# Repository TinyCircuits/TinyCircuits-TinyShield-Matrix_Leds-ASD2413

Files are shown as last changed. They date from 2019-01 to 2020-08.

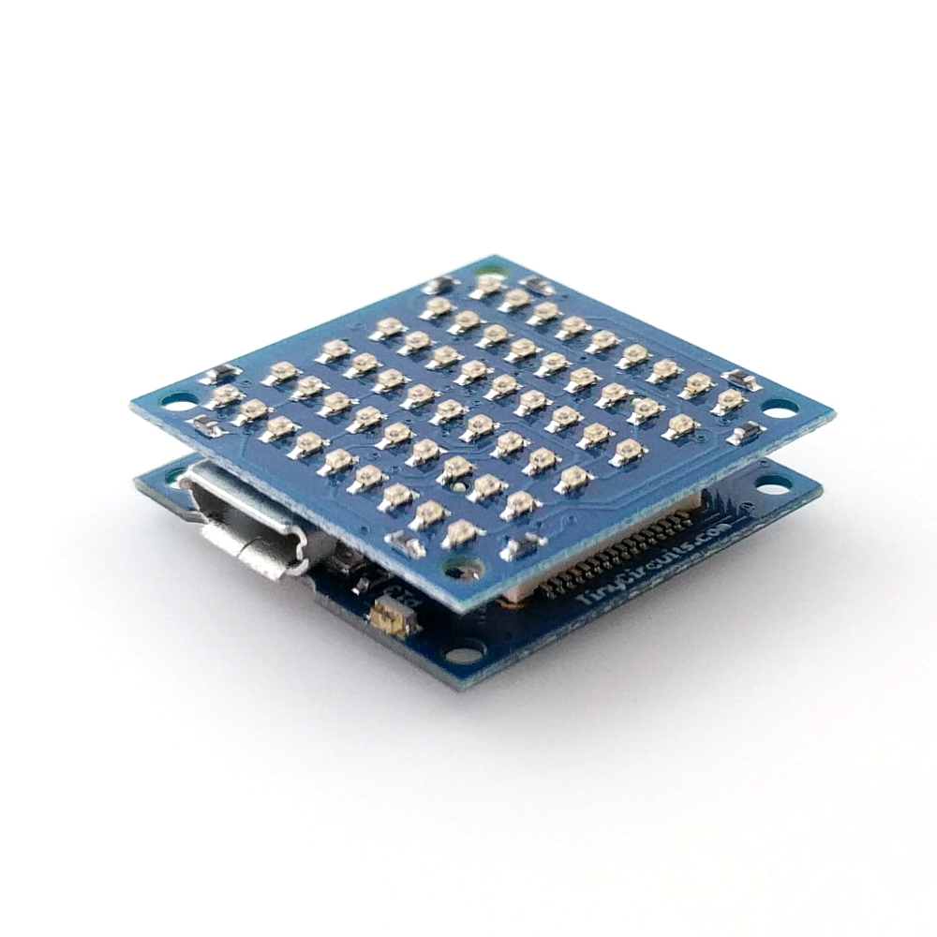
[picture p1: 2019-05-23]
images/ASD2413-R-LG-Tutorial-Image-03.jpg

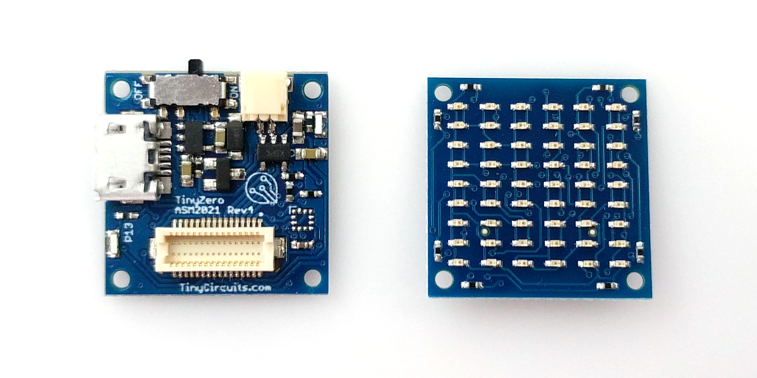
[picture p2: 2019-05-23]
images/ASD2413-R-LG-Tutorial-Image-02.jpg

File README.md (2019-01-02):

# TinyCircuits TinyShield Matrix LEDs
# ASD2413 Rev2

The design files are located under design_files/ for the TinyCircuits ASD2413 Rev 2 PCB.  This is a Tiny shield board (Square Version, 20mm x 20mm) that has a 54 LEDs in a 6x9 Matrix.

Format is in Cadsoft Eagle format - Eagle version 6.2 was used for the original design.

For more infomation on this, check out the product page at TinyCircuits.com:  https://tinycircuits.com/collections/leds-displays/products/matrix-led-tinyshield

# License:

Design by TinyCircuits.
All design files are released under the Creative Commons Attribution Share-Alike 3.0 License, see the following link for details: http://creativecommons.org/licenses/by-sa/3.0

All text above must be included in any redistribution or derived design

This project uses designs and concepts developed as part of the Arduino project and the LilyPad project.  The TinyCircuits design files themselves (schematics, PCB and libraries) are not directly derived from these works' design files and have been created new, however the concepts and basic architecture behind the TinyDuino and TinyLily products are derived and we thank the hard work of the organizations below for their contributions to open-source hardware:
  
Original Arduino Uno Design by Team Arduino

LilyPad Arduino Design by Leah Buechley and Sparkfun Electronics

Please support the open-source hardware community

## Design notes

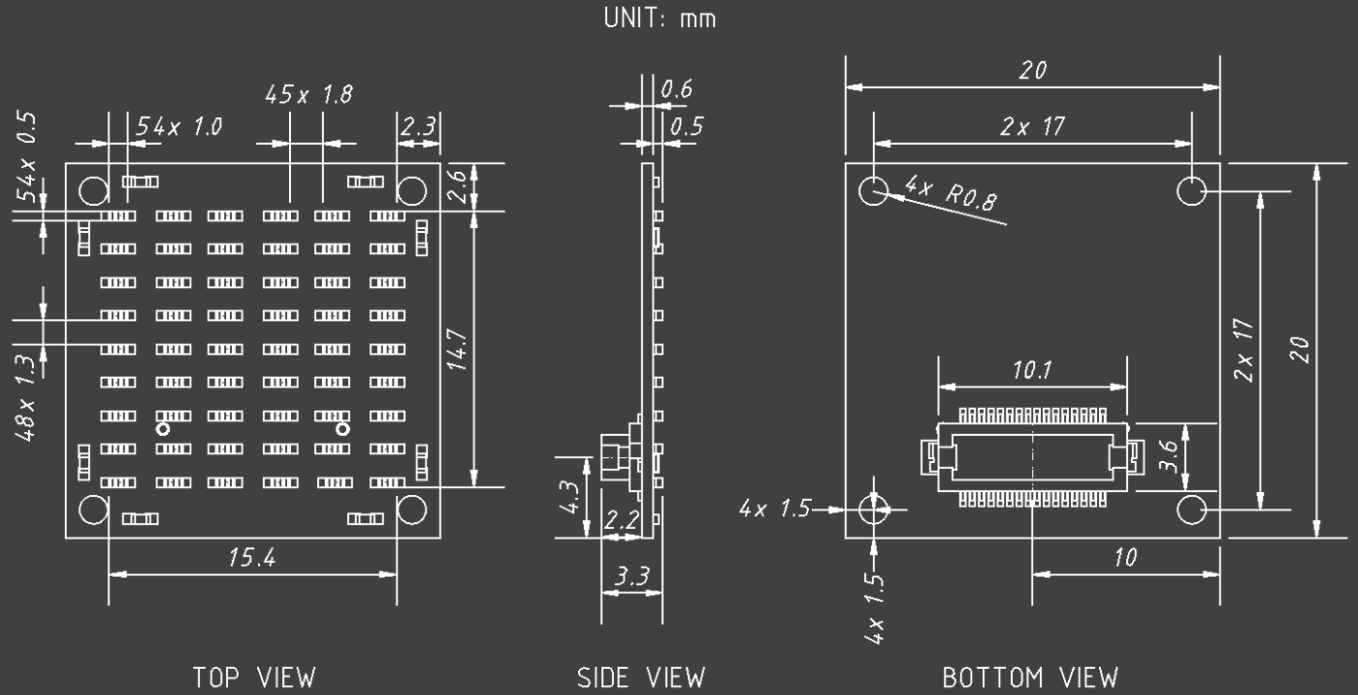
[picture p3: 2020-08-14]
cad/TinyShield_MATRIX_LED_ASD2413_REV2-DETAILED_DRAWING_COMPACT-PNG.png

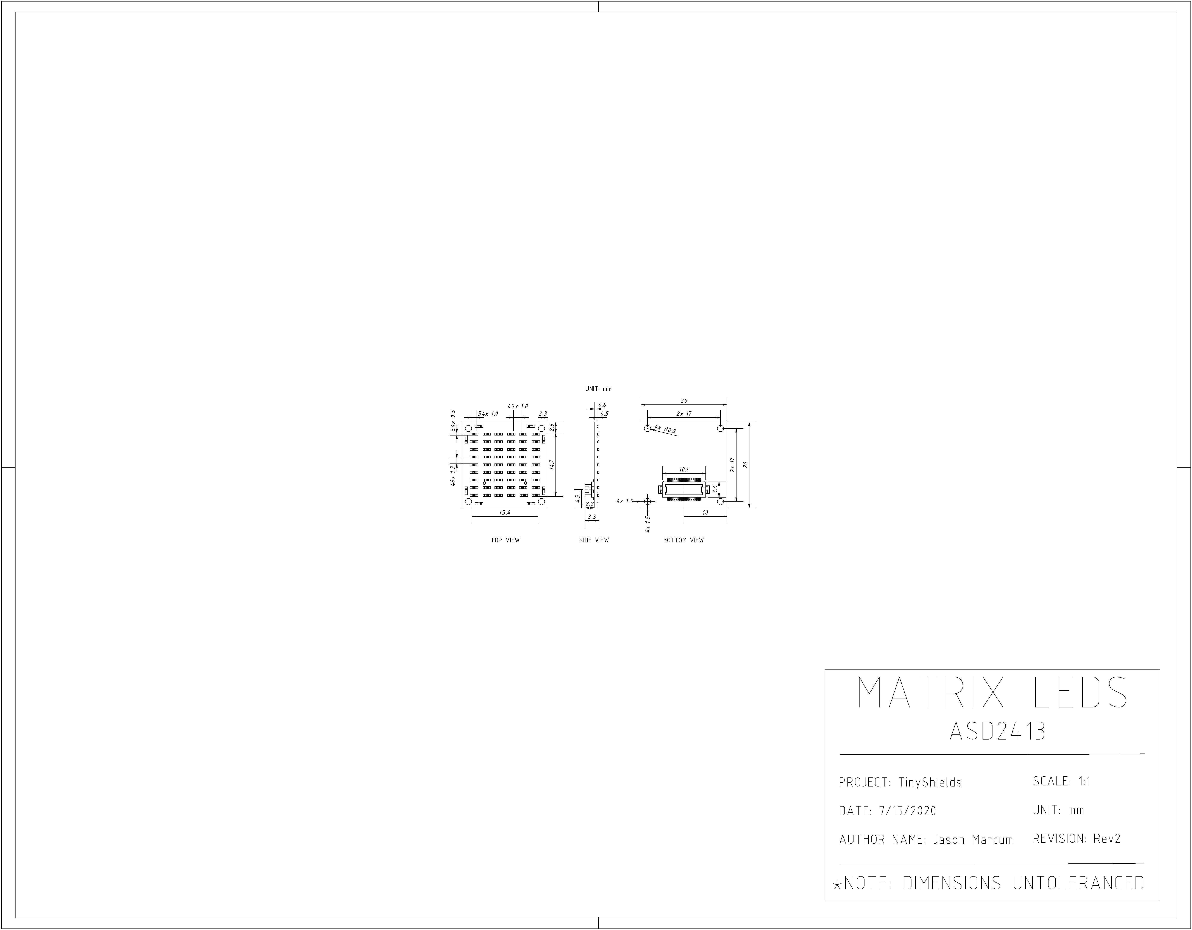
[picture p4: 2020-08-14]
cad/TinyShield_MATRIX_LED_ASD2413_REV2-DETAILED_DRAWING-PNG.png

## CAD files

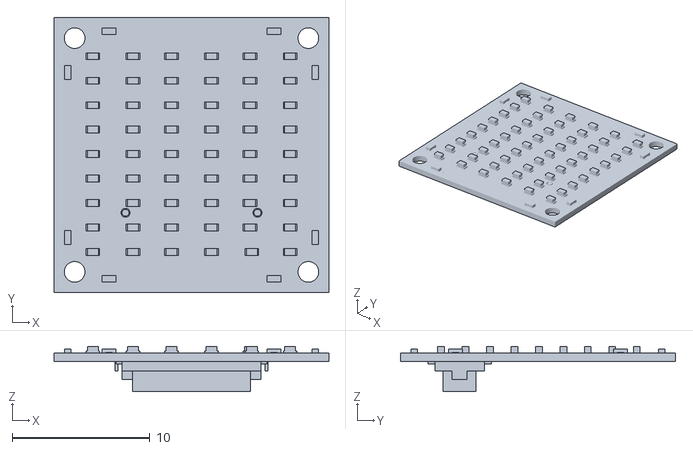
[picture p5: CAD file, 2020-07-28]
cad/TinyShield_MATRIX_LED_ASD2413_REV2-STL.stl
20.0 x 20.0 x 3.30

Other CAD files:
cad/TinyShield_MATRIX_LED_ASD2413_REV2-DETAILED_DRAWING-DXF.dxf

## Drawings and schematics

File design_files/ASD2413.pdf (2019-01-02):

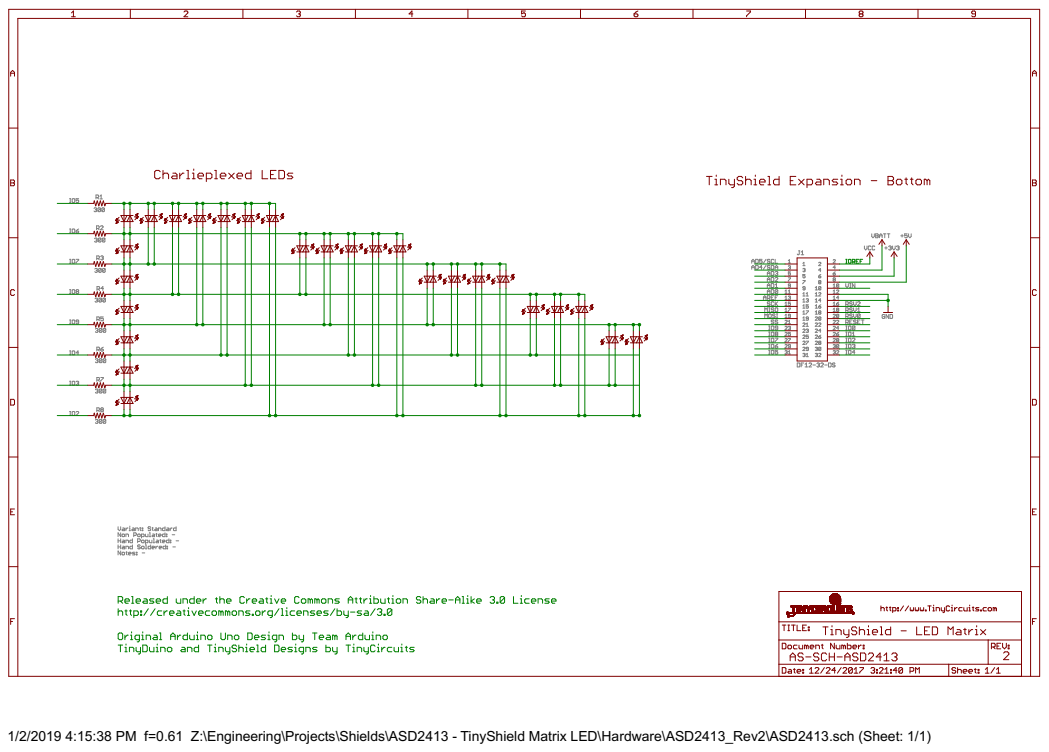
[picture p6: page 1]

1/2/2019 4:15:38 PM f=0.61 Z:\Engineering\Projects\Shields\ASD2413 - TinyShield Matrix LED\Hardware\ASD2413_Rev2\ASD2413.sch (Sheet: 1/1)

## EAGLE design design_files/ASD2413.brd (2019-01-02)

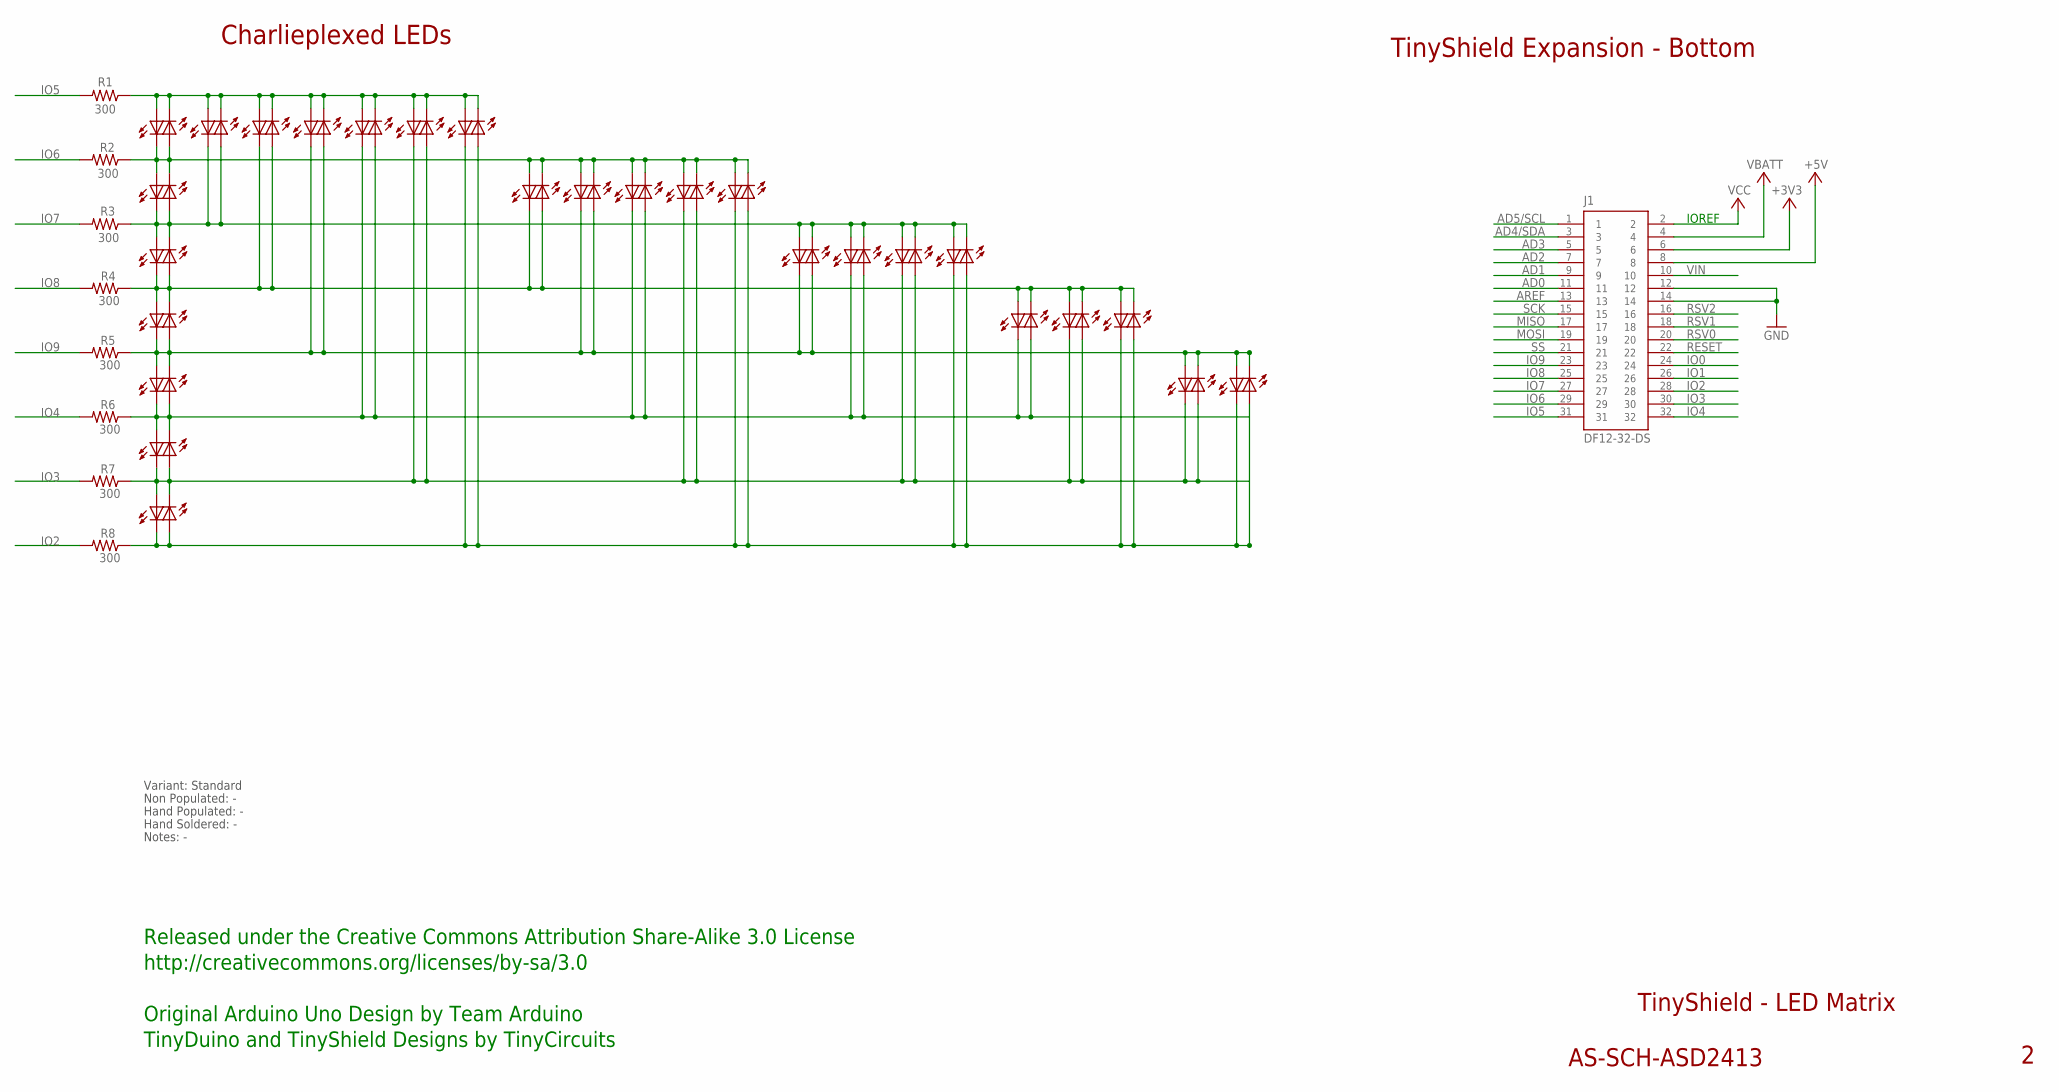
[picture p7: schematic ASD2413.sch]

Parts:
D1, D2, D3, D4, D5, D6, D7, D8, D9, D10, D11, D12, D13, D14, D15, D16, D17, D18, D19, D20, D21, D22, D23, D24, D25, D26, D27, D28, D29, D30, D31, D32, D33, D34, D35, D36, D37, D38, D39, D40, D41, D42, D43, D44, D45, D46, D47, D48, D49, D50, D51, D52, D53, D54: GREEN; 0402_LED; PARTNO AS-ITM-00038
J1: DF12-32-DS; PARTNO AS-ITM-00012
R1, R6, R7, R8: 300; 0402; PARTNO AS-ITM-00016
R2, R3, R4, R5: 300; 0402

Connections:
+3V3: J1.6
+5V: J1.8
AD0: J1.11
AD1: J1.9
AD2: J1.7
AD3: J1.5
AD4/SDA: J1.3
AD5/SCL: J1.1
AREF: J1.13
GND: J1.12, J1.14
IO0: J1.24
IO1: J1.26
IO2: J1.28, R8.2
IO3: J1.30, R7.2
IO4: J1.32, R6.2
IO5: J1.31, R1.2
IO6: J1.29, R2.2
IO7: J1.27, R3.2
IO8: J1.25, R4.2
IO9: J1.23, R5.2
MISO: J1.17
MOSI: J1.19
unnamed: D1.2 (C), D2.1 (A), D8.1 (A), D9.2 (C), D27.1 (A), D28.2 (C), D29.1 (A), D30.2 (C), D31.1 (A), D32.2 (C), D33.1 (A), D34.2 (C), D35.1 (A), D36.2 (C), R2.1
unnamed: D3.2 (C), D4.1 (A), D10.1 (A), D11.2 (C), D17.2 (C), D18.1 (A), D27.2 (C), D28.1 (A), D45.1 (A), D46.2 (C), D47.1 (A), D48.2 (C), D49.1 (A), D50.2 (C), R4.1
unnamed: D5.2 (C), D6.1 (A), D12.1 (A), D13.2 (C), D21.2 (C), D22.1 (A), D31.2 (C), D32.1 (A), D39.2 (C), D40.1 (A), D45.2 (C), D46.1 (A), R6.1
unnamed: D7.2 (C), D14.1 (A), D25.2 (C), D26.1 (A), D35.2 (C), D36.1 (A), D43.2 (C), D44.1 (A), D49.2 (C), D50.1 (A), D53.2 (C), D54.1 (A), R8.1
unnamed: D1.1 (A), D8.2 (C), D15.1 (A), D16.2 (C), D17.1 (A), D18.2 (C), D19.1 (A), D20.2 (C), D21.1 (A), D22.2 (C), D23.1 (A), D24.2 (C), D25.1 (A), D26.2 (C), R1.1
unnamed: D2.2 (C), D3.1 (A), D9.1 (A), D10.2 (C), D15.2 (C), D16.1 (A), D37.1 (A), D38.2 (C), D39.1 (A), D40.2 (C), D41.1 (A), D42.2 (C), D43.1 (A), D44.2 (C), R3.1
unnamed: D6.2 (C), D7.1 (A), D13.1 (A), D14.2 (C), D23.2 (C), D24.1 (A), D33.2 (C), D34.1 (A), D41.2 (C), D42.1 (A), D47.2 (C), D48.1 (A), D51.2 (C), D52.1 (A), R7.1
unnamed: D4.2 (C), D5.1 (A), D11.1 (A), D12.2 (C), D19.2 (C), D20.1 (A), D29.2 (C), D30.1 (A), D37.2 (C), D38.1 (A), D51.1 (A), D52.2 (C), D53.1 (A), D54.2 (C), R5.1
RESET: J1.22
RSV0: J1.20
RSV1: J1.18
RSV2: J1.16
SCK: J1.15
SS: J1.21
VBATT: J1.4
VCC: J1.2
VIN: J1.10

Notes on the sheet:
TinyShield Expansion - Bottom
Charlieplexed LEDs
TinyShield - LED Matrix
AS-SCH-ASD2413
IOREF
Released under the Creative Commons Attribution Share-Alike 3.0 License
http://creativecommons.org/licenses/by-sa/3.0
Original Arduino Uno Design by Team Arduino
TinyDuino and TinyShield Designs by TinyCircuits
Variant: Standard
Non Populated: -
Hand Populated: -
Hand Soldered: -
Notes: -

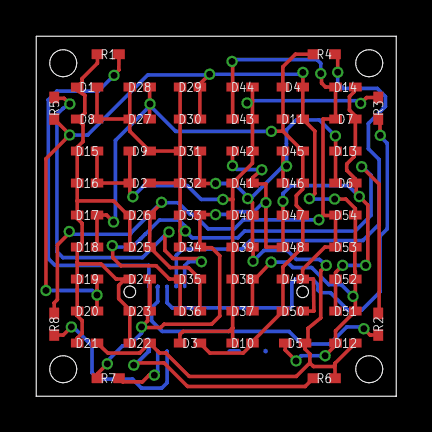
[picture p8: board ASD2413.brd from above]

Board: 2 copper layers, 20.0 x 20.0 mm, 64 parts (1 on the bottom side), 17 nets.

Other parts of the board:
U$1: DOCFIELD-TINYCIRCUITS-PCB

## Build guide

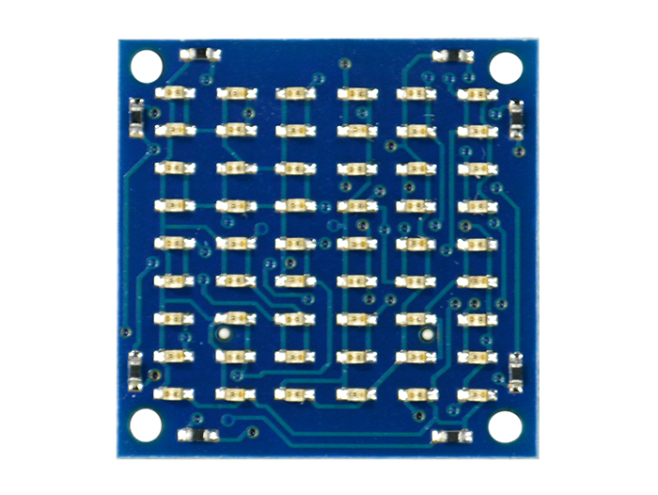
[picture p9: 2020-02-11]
images/ASD2413-R-LG-Tutorial-Image-01.png

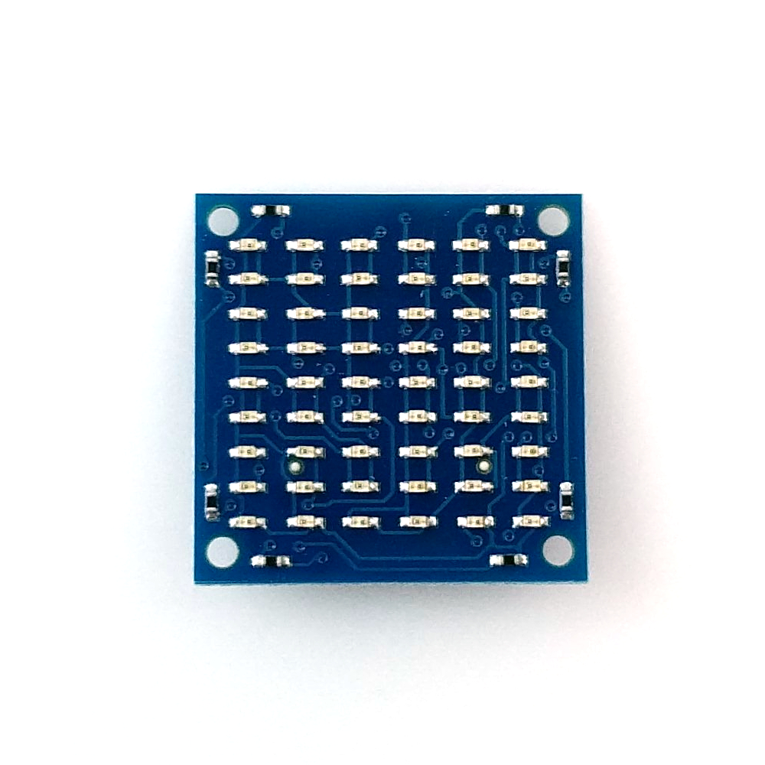
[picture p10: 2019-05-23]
images/ASD2413-R-LG-Tutorial-Image-01.jpg

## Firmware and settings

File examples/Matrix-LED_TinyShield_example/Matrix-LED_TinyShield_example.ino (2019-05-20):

/*
  TinyDuino Matrix LED TinyShield Example Sketch
  
  This example illuminates one LED at a time,
  iterating through each LED in the matrix.
  
  Written 10 January 2019
  By Hunter Hykes
  Modified 
  By 
  
  https://TinyCircuits.com
*/

const int highpin[54] = {
  5, 8, 6, 2, 8, 2,
  6, 6, 9, 7, 9, 3,
  5, 7, 6, 3, 8, 3,
  7, 6, 4, 7, 4, 4,    
  5, 2, 6, 4, 8, 2,
  8, 5, 3, 7, 3, 9,
  5, 3, 6, 9, 8, 3,
  9, 5, 2, 7, 2, 9,
  5, 4, 7, 8, 9, 4   
};

const int lowpin[54] = {
  6, 6, 9, 7, 9, 3,
  5, 8, 6, 2, 8, 2,
  7, 6, 4, 7, 4, 4,
  5, 7, 6, 3, 8, 3,    
  8, 5, 3, 7, 3, 9,
  5, 2, 6, 4, 8, 2,
  9, 5, 2, 7, 2, 9,
  5, 3, 6, 9, 8, 3,
  4, 5, 8, 7, 4, 9
};

void setup() {
  matrixOff();
}

void loop() {
  for(int i = 0; i < 54; i++) {
    lightLED(i);
    delay(50);
    matrixOff();
  }
}

void matrixOff() { //sets each IO pin used by the board LOW
  for(int i = 2; i < 10; i++) {
    pinMode(i, INPUT);
    digitalWrite(i, LOW);
  }
}

void lightLED(int ledNum) { //sets the specified LED on (0-53)
  digitalWrite(highpin[ledNum],HIGH);
  digitalWrite(lowpin[ledNum],LOW);
  pinMode(highpin[ledNum],OUTPUT);
  pinMode(lowpin[ledNum],OUTPUT);
}

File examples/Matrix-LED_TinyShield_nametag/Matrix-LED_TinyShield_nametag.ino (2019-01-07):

/*
  LED Matrix TinyShield Nametag Example
  
  This example creates a scrolling nametag on the LED matrix
  given a specific string.
  This example code is in the public domain.

  Written 28 January 2015
  By Tony Batey
  Modified 07 January 2019
  By Hunter Hykes

  https://TinyCircuits.com
*/

/*
  MAKE THE FOLLORING CHANGES TO THE CHARLIEPLEXING.H AND .CPP FILES:

  In Charlieplexing.h change the DISPLAY_COLS definition to 6 and the DISPLAY_ROWS definition to 9

    #define DISPLAY_COLS 6      // Number of columns in the display
    #define DISPLAY_ROWS 9      // Number of rows in the display
  

  In Charlieplexing.cpp change the ledMap array to match the following:

    const LEDPosition PROGMEM ledMap[54] = {
      L(5, 6), L(8, 6), L(6, 9), L(2, 7), L(8, 9), L(2,3),
      L(6, 5), L(6, 8), L(9, 6), L(7, 2), L(9, 8), L(3,2),
      L(5, 7), L(7, 6), L(6, 4), L(3, 7), L(8, 4), L(3,4),
      L(7, 5), L(6, 7), L(4, 6), L(7, 3), L(4, 8), L(4,3),
      L(5, 8), L(2, 5), L(6, 3), L(4, 7), L(8, 3), L(2,9),
      L(8, 5), L(5, 2), L(3, 6), L(7, 4), L(3, 8), L(9,2),
      L(5, 9), L(3, 5), L(6, 2), L(9, 7), L(8, 2), L(3,9),
      L(9, 5), L(5, 3), L(2, 6), L(7, 9), L(2, 8), L(9,3),
      L(5, 4), L(4, 5), L(7, 8), L(8, 7), L(9, 4), L(4,9)
    };
*/

#include "Charliplexing.h"
#include "Font.h"
#include "Arduino.h"

void setup()  
{
  LedSign::Init();
}

static const char test[]="HI EVERYBODY!  "; //Put whatever you want displayed 
											                      //inside the quotes!
void loop()                     
{
  for (int8_t x=DISPLAY_COLS, i=0;; x--) {
	  LedSign::Clear();
    for (int8_t x2=x, i2=i; x2<DISPLAY_COLS;) {
      int8_t w = Font::Draw(test[i2], x2, 0);
	    x2 += w, i2 = (i2+1)%strlen(test);
	    if (x2 <= 0)	// off the display completely?
        x = x2, i = i2;
	  }
      delay(80);
  }
}

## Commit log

2019-01-02 update format
    [ASD2413.brd, ASD2413.sch]
2020-07-28 Add CAD data
    [TinyShield_MATRIX_LED_ASD2413_REV2-DETAILED_DRAWING-DXF.dxf, TinyShield_MATRIX_LED_ASD2413_REV2-STL.stl]
2020-08-14 Update CAD drawing
